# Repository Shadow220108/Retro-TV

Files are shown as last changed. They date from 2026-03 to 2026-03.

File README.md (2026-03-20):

<<<<<<< HEAD
| Retro-TV |
| --- |
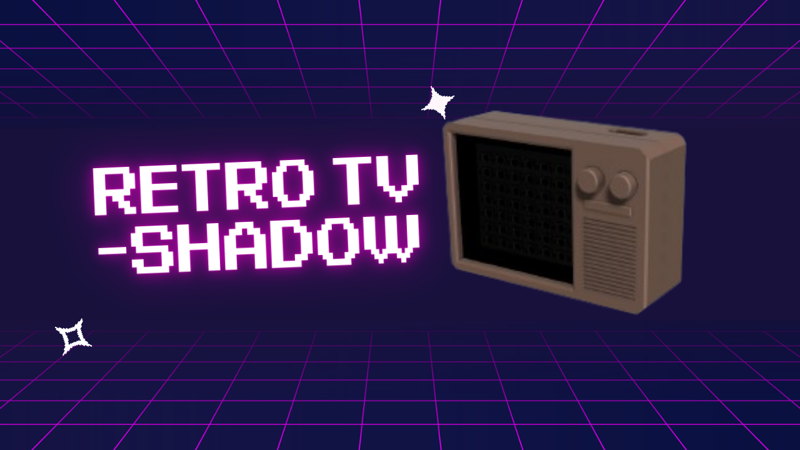
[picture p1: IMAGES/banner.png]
Banner
|  | 

Its a LED Matrix display of 7x7 LEDs, in a vintage television style case!  

### PCB
The PCB is designed to be compact with about 50 LEDs in just about 60mm of space
| LED Matrix |
| --- |
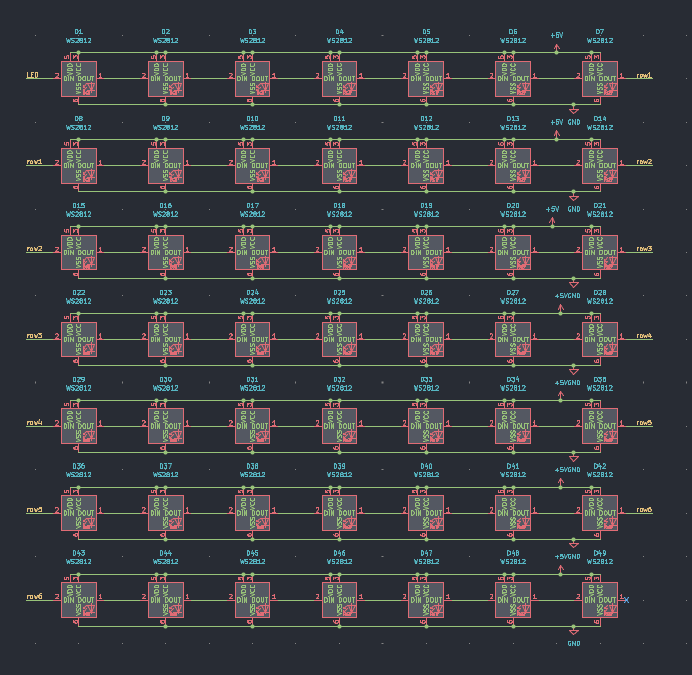
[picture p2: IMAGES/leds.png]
Schematics
|  | 

| MCU |
| --- |
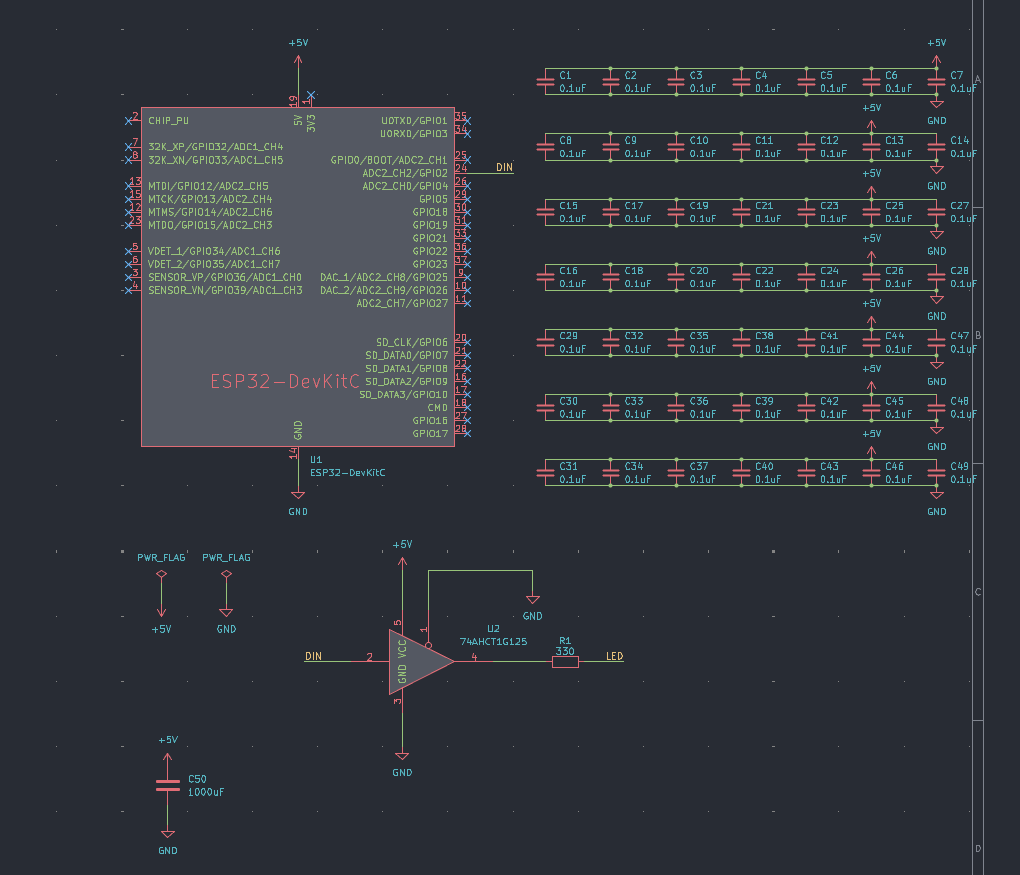
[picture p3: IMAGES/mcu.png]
PCB All Layers
|  |

| PCB (All Layers)|
| --- |
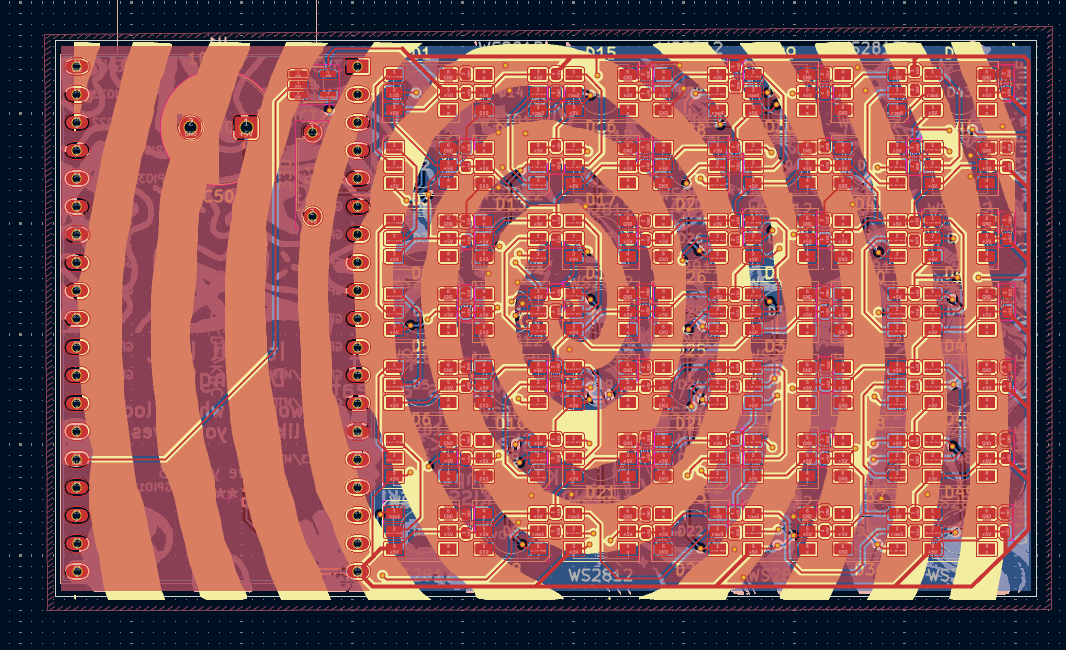
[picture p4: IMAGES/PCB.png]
|  |
| --- |
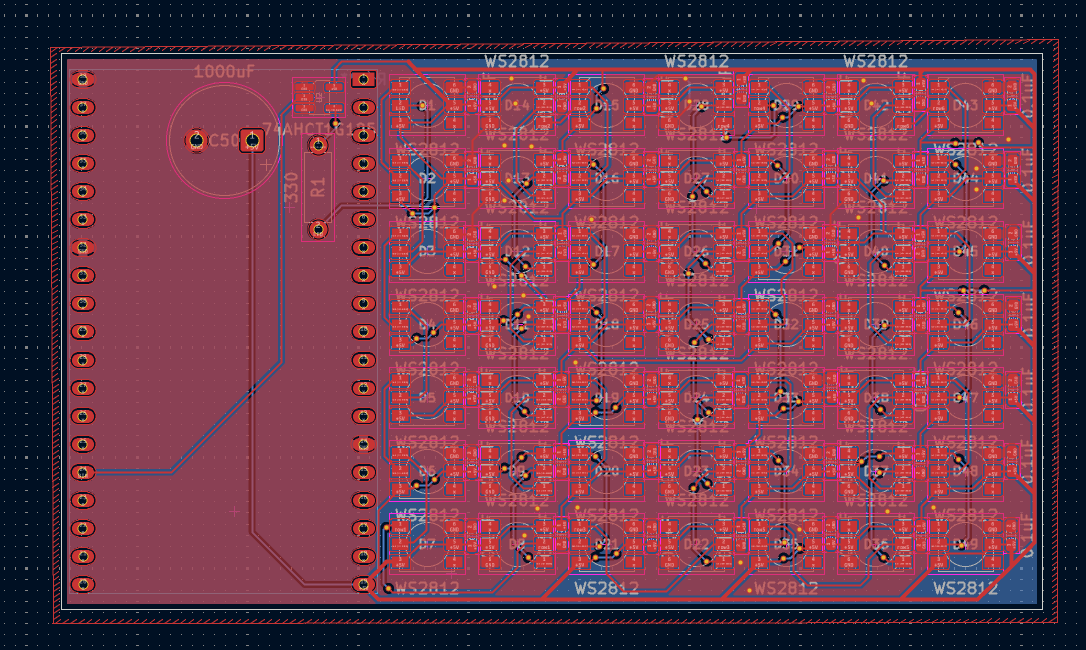
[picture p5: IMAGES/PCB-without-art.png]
|  |

| PS : Some PCB art|
| --- |
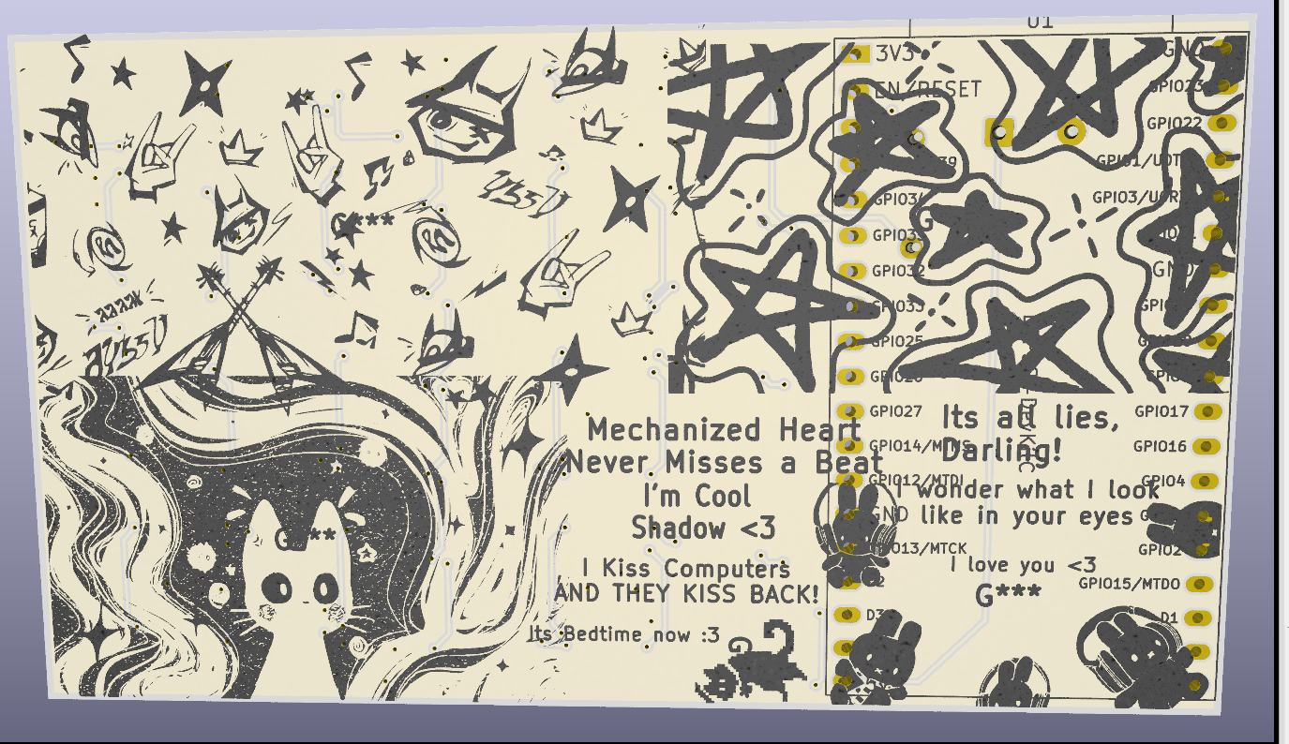
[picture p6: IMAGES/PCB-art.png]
|  |
| --- |
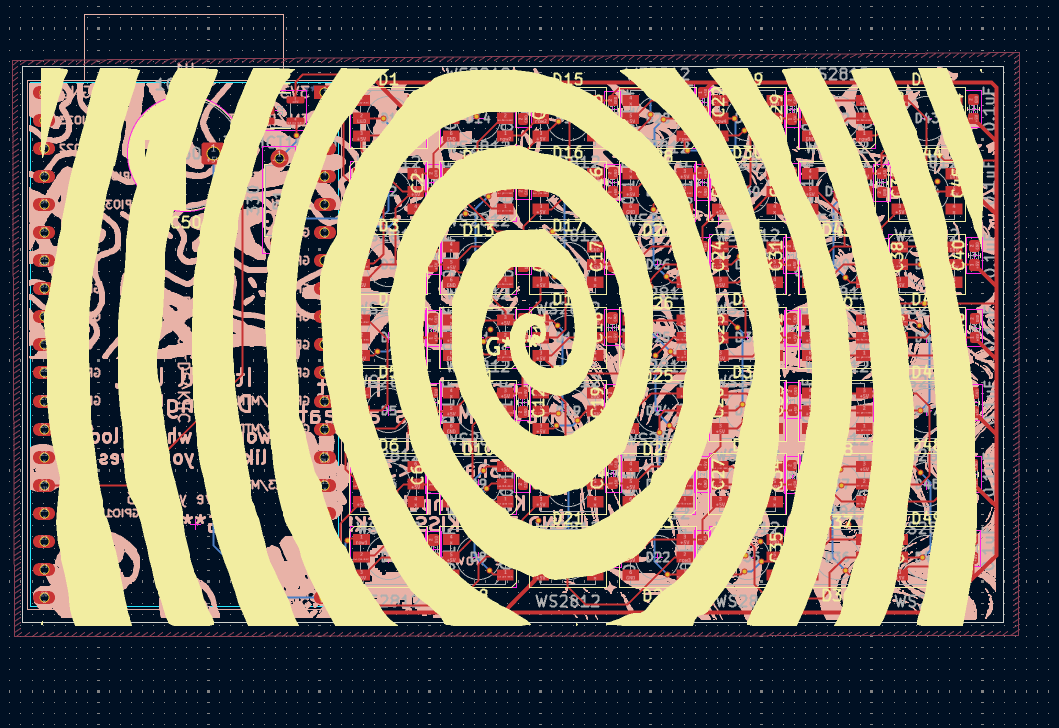
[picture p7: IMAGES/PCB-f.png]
|  |
| --- |
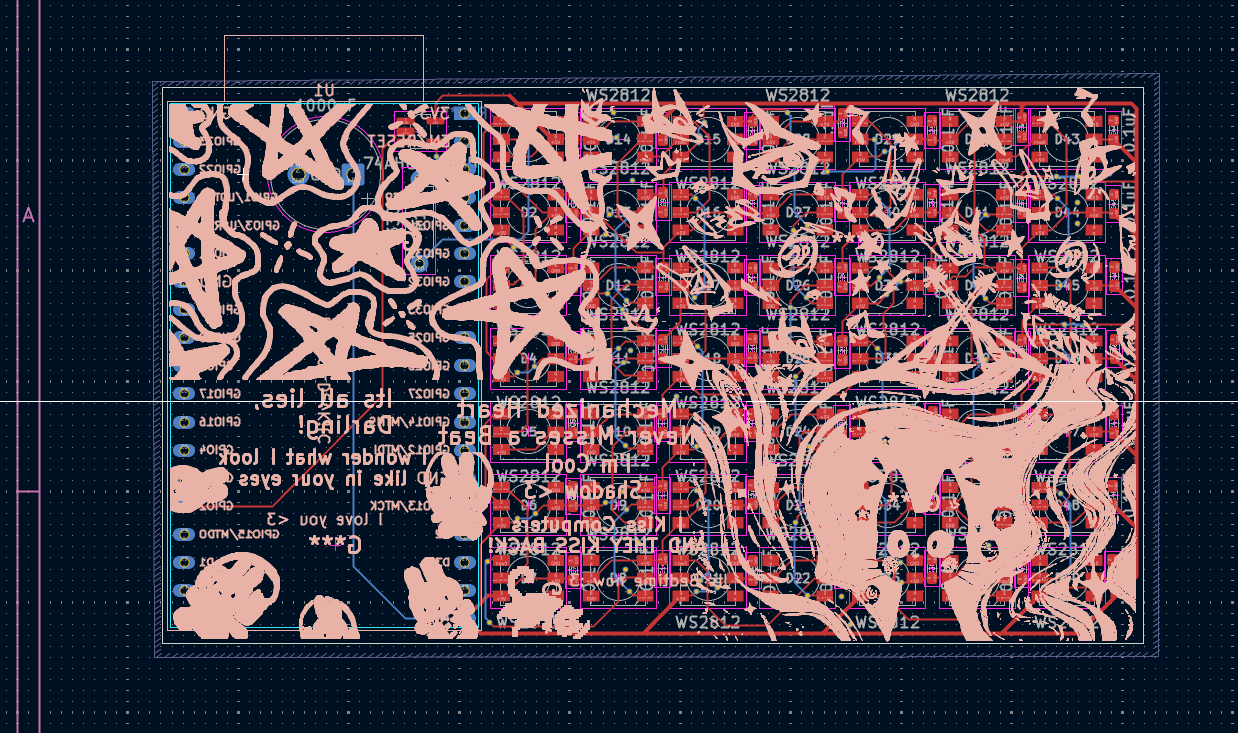
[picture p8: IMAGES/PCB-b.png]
|  |

## Case

The case is designed to be 3D printed and attached with magnets. The bottom case, top case, plate, and knob are all designed to be printed.

| CAD|
| --- |
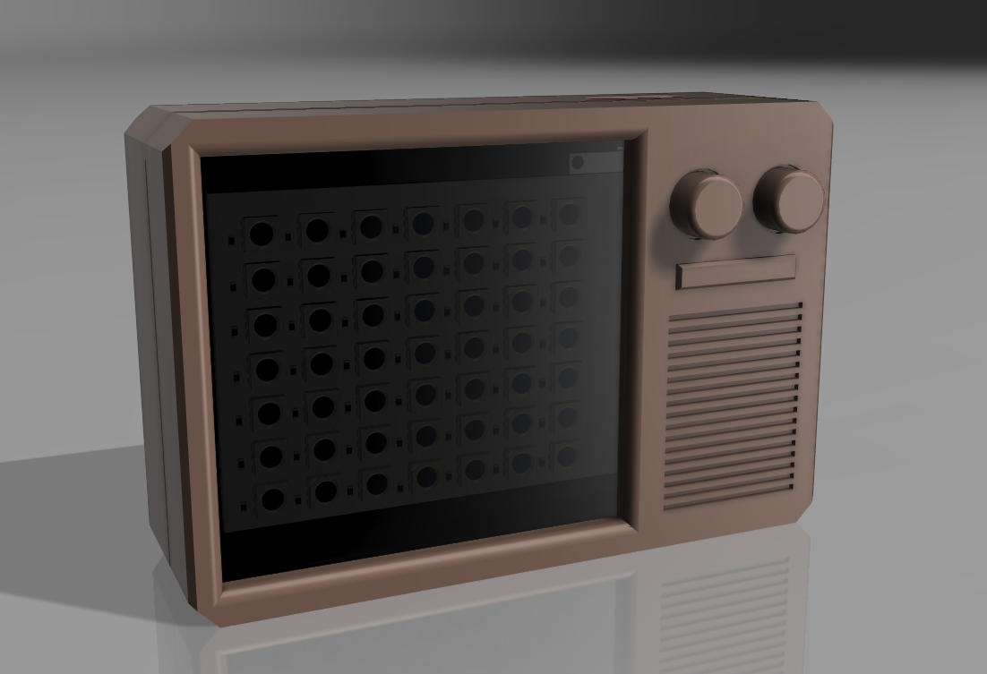
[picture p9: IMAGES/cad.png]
|  |
| --- |
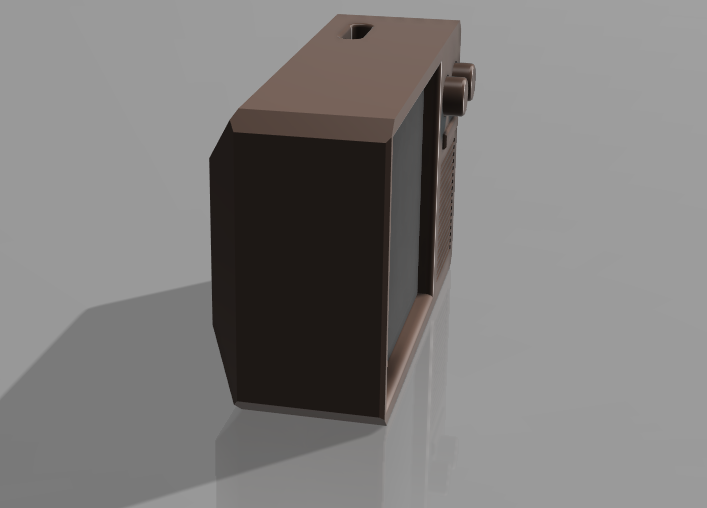
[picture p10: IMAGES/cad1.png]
|  |

## BOM 
|Name |Purpose |Cost Per Item (USD)|Quantity|Total (USD)|Link |Distributor |
|---|---|---|---|---|---|---|
|3D Prints |to get prints from #printing-legion |5.00 |1 |5.00 | |#printing-legion|
|Soldering Hotplate |To solder the mini leds |0.00 |1 |0.00 | |Self sourced |
|Soldering paste |to solder the smd components |4.50 |1 |4.50 |https://www.amazon.in/gp/product/B0F9VTZJ5R?smid=A32I52VHFPY5IG&psc=1 |Amazon |
|Alkin 65W adapter |To use the soldering hotplate to solder|8.54 |1 |8.54 |https://www.amazon.in/AILKIN-Charging-Adapter-Multi-Port-Compatible/dp/B0GH81K2LK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|Amazon |
|Neodimium magnets |to attach the top and bottom case |3.00 |1 |3.00 |https://www.amazon.in/gp/product/B0G2SW9GZL?smid=AP7MBNLZTN3FQ&psc=1 |amazon |
|330 ohm resistor ( 10 moq ) |to not burst the leds |0.11 |1 |0.11 |https://robu.in/product/330-ohm-1w-metal-film-resistor-pack-of-40/ |robu.in |
|1000uF capacitor |Bulk capacitor |0.11 |1 |0.11 |https://robu.in/product/1000uf-25v-electrolytic-capacitor-dip-pack-of-5/ |robu.in |
|0.1uF capacitors |to reduce electrical noise |0.07 |50 |3.75 |https://probots.co.in/0-1-uf-50v-smd-ceramic-capacitor-0603-package.html |probots.co |
|74AHCT1G125GV |Level shifter for LEDs |0.16 |1 |0.16 |https://robu.in/product/74ahct1g125gv125-nexperia-1-8ma-4-5v5-5v-8ma-1-sot-753-buffers-drivers-receivers-transceivers-rohs/ |robu,in |
|SMD 5050 LEDs |For the display |0.04 |50 |2.00 |https://www.flyrobo.in/5050-red-green-blue-rgb-smd-led |flyrobo.in |
|ESP32 Devboard |MCU to control the LEDs |4.62 |1 |4.62 |https://www.flyrobo.in/esp-wroom-32-nodemcu-module?search=esp32&description=true |flyrobo.in |
|PCB ( 5 MOQ ) |to solder all the components |13.02 |1 |13.02 | |JLCPCB |
=======
| Retro-TV |
| --- |
| Banner | 

Its a LED Matrix display of 7x7 LEDs, in a vintage television style case!  

### PCB
The PCB is designed to be compact with about 50 LEDs in just about 60mm of space
| LED Matrix |
| --- |
| Schematics | 

| MCU |
| --- |
| PCB All Layers |

| PCB (All Layers)|
| --- |
| PCB1 |
| --- |
| PCB1 |

| PS : Some PCB art|
| --- |
| Quotes |
| --- |
| Quotes |
| --- |
| Quotes |

## Case

The case is designed to be 3D printed and attached with magnets. The bottom case, top case, plate, and knob are all designed to be printed.

| CAD|
| --- |
| Case Full |
| --- |
| Case Full |

## BOM 
|Name |Purpose |Cost Per Item (USD)|Quantity|Total (USD)|Link |Distributor |
|---|---|---|---|---|---|---|
|3D Prints |to get prints from #printing-legion |5.00 |1 |5.00 | |#printing-legion|
|Soldering Hotplate |To solder the mini leds |0.00 |1 |0.00 | |Self sourced |
|Soldering paste |to solder the smd components |4.50 |1 |4.50 |https://www.amazon.in/gp/product/B0F9VTZJ5R?smid=A32I52VHFPY5IG&psc=1 |Amazon |
|Alkin 65W adapter |To use the soldering hotplate to solder|8.54 |1 |8.54 |https://www.amazon.in/AILKIN-Charging-Adapter-Multi-Port-Compatible/dp/B0GH81K2LK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|Amazon |
|Neodimium magnets |to attach the top and bottom case |3.00 |1 |3.00 |https://www.amazon.in/gp/product/B0G2SW9GZL?smid=AP7MBNLZTN3FQ&psc=1 |amazon |
|330 ohm resistor ( 10 moq ) |to not burst the leds |0.11 |1 |0.11 |https://robu.in/product/330-ohm-1w-metal-film-resistor-pack-of-40/ |robu.in |
|1000uF capacitor |Bulk capacitor |0.11 |1 |0.11 |https://robu.in/product/1000uf-25v-electrolytic-capacitor-dip-pack-of-5/ |robu.in |
|0.1uF capacitors |to reduce electrical noise |0.07 |50 |3.75 |https://probots.co.in/0-1-uf-50v-smd-ceramic-capacitor-0603-package.html |probots.co |
|74AHCT1G125GV |Level shifter for LEDs |0.16 |1 |0.16 |https://robu.in/product/74ahct1g125gv125-nexperia-1-8ma-4-5v5-5v-8ma-1-sot-753-buffers-drivers-receivers-transceivers-rohs/ |robu,in |
|SMD 5050 LEDs |For the display |0.04 |50 |2.00 |https://www.flyrobo.in/5050-red-green-blue-rgb-smd-led |flyrobo.in |
|ESP32 Devboard |MCU to control the LEDs |4.62 |1 |4.62 |https://www.flyrobo.in/esp-wroom-32-nodemcu-module?search=esp32&description=true |flyrobo.in |
|PCB ( 5 MOQ ) |to solder all the components |13.02 |1 |13.02 | |JLCPCB |
>>>>>>> c8a452447a518745ea2085dd8981138584917547

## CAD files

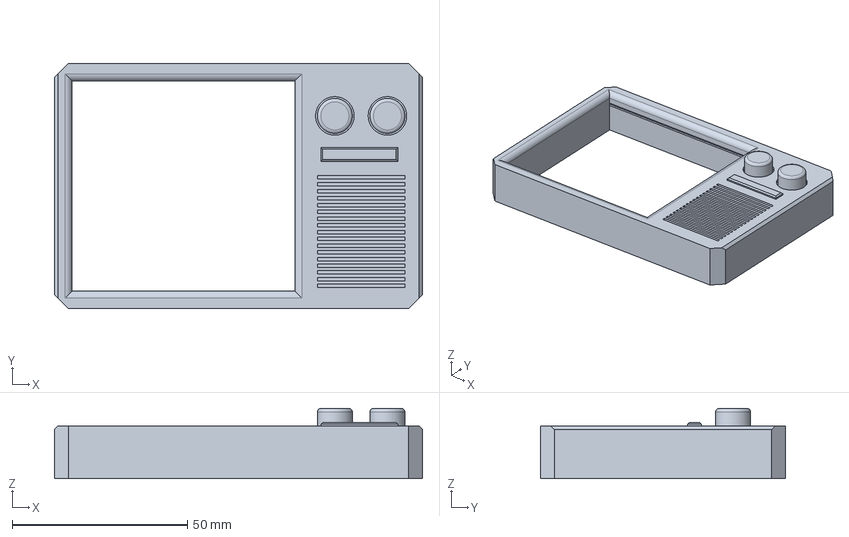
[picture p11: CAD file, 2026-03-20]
CAD/top.step
105.0 x 70.0 x 20.0 mm

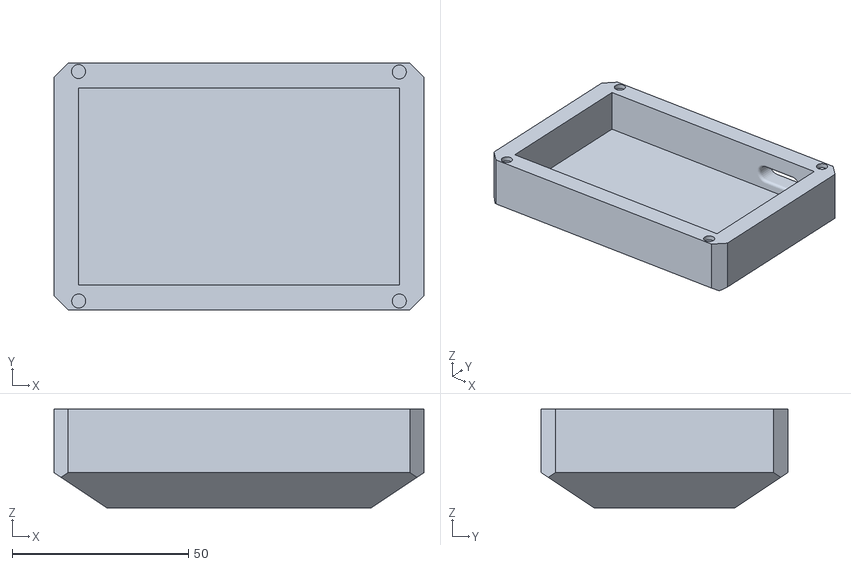
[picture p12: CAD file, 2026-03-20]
PRODUCTION/bottom.stl
105.0 x 70.0 x 28.0

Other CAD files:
CAD/bottom.step
PRODUCTION/top.stl

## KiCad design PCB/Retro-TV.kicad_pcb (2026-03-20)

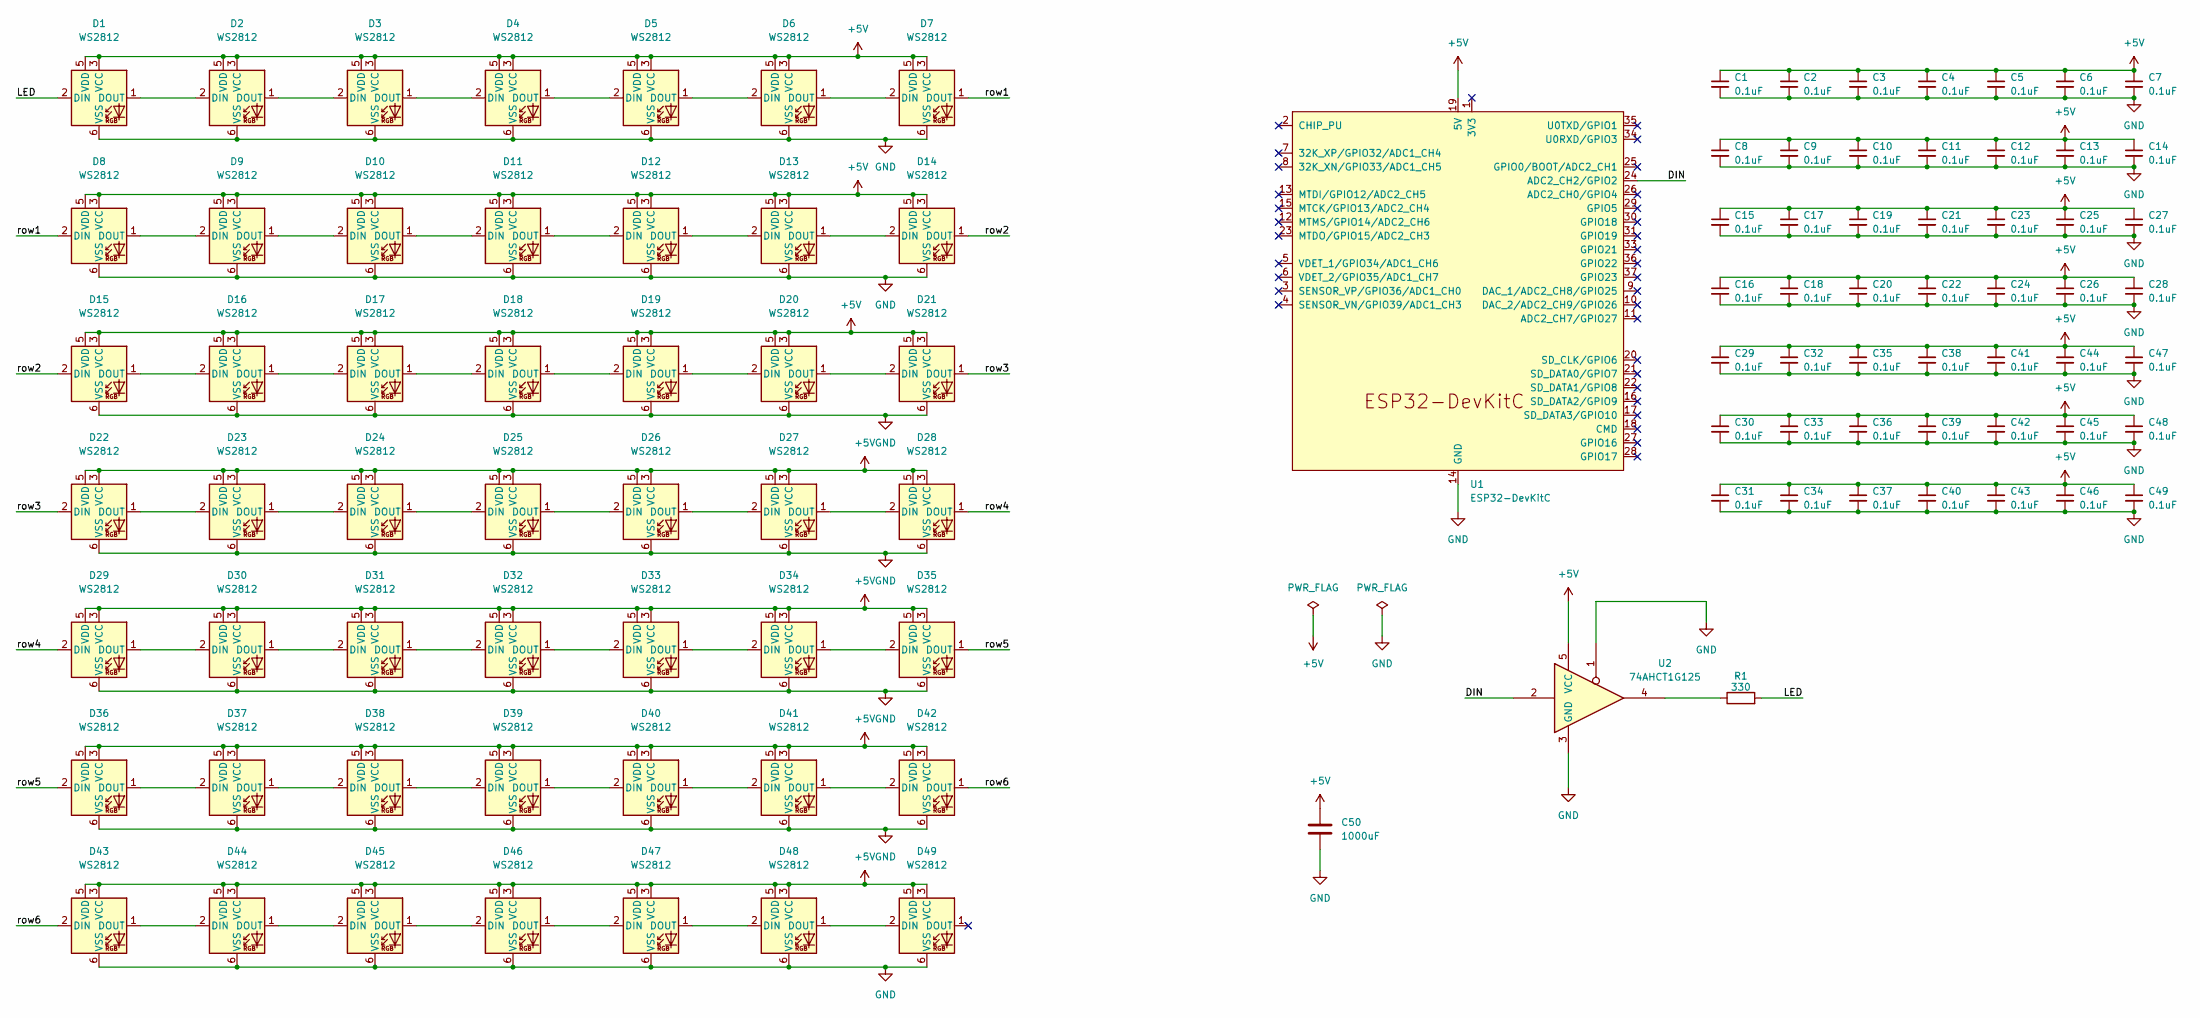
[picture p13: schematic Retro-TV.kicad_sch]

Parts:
C1, C2, C3, C4, C5, C6, C7, C8, C9, C10, C11, C12, C13, C14, C15, C16, C17, C18, C19, C20, C21, C22, C23, C24, C25, C26, C27, C28, C29, C30, C31, C32, C33, C34, C35, C36, C37, C38, C39, C40, C41, C42, C43, C44, C45, C46, C47, C48, C49: 0.1uF; C_0603_1608Metric_Pad1.08x0.95mm_HandSolder
C50: 1000uF; CP_Radial_D10.0mm_P5.00mm
D1, D2, D3, D4, D5, D6, D7, D8, D9, D10, D11, D12, D13, D14, D15, D16, D17, D18, D19, D20, D21, D22, D23, D24, D25, D26, D27, D28, D29, D30, D31, D32, D33, D34, D35, D36, D37, D38, D39, D40, D41, D42, D43, D44, D45, D46, D47, D48, D49: WS2812; LED_WS2812_PLCC6_5.0x5.0mm_P1.6mm
R1: 330; R_Axial_DIN0207_L6.3mm_D2.5mm_P7.62mm_Horizontal
U1: ESP32-DevKitC
U2: 74AHCT1G125; SOT-23-5_HandSoldering

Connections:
+5V: C1.1, C2.1, C3.1, C4.1, C5.1, C6.1, C7.1, C8.1, C9.1, C10.1, C11.1, C12.1, C13.1, C14.1, C15.1, C16.1, C17.1, C18.1, C19.1, C20.1, C21.1, C22.1, C23.1, C24.1, C25.1, C26.1, C27.1, C28.1, C29.1, C30.1, C31.1, C32.1, C33.1, C34.1, C35.1, C36.1, C37.1, C38.1, C39.1, C40.1, C41.1, C42.1, C43.1, C44.1, C45.1, C46.1, C47.1, C48.1, C49.1, C50.1, D1.3 (VCC), D1.5 (VDD), D2.3 (VCC), D2.5 (VDD), D3.3 (VCC), D3.5 (VDD), D4.3 (VCC), D4.5 (VDD), D5.3 (VCC), D5.5 (VDD), D6.3 (VCC), D6.5 (VDD), D7.3 (VCC), D7.5 (VDD), D8.3 (VCC), D8.5 (VDD), D9.3 (VCC), D9.5 (VDD), D10.3 (VCC), D10.5 (VDD), D11.3 (VCC), D11.5 (VDD), D12.3 (VCC), D12.5 (VDD), D13.3 (VCC), D13.5 (VDD), D14.3 (VCC), D14.5 (VDD), D15.3 (VCC), D15.5 (VDD), D16.3 (VCC), D16.5 (VDD), D17.3 (VCC), D17.5 (VDD), D18.3 (VCC), D18.5 (VDD), D19.3 (VCC), D19.5 (VDD), D20.3 (VCC), D20.5 (VDD), D21.3 (VCC), D21.5 (VDD), D22.3 (VCC), D22.5 (VDD), D23.3 (VCC), D23.5 (VDD), D24.3 (VCC), D24.5 (VDD), D25.3 (VCC), D25.5 (VDD), D26.3 (VCC), D26.5 (VDD), D27.3 (VCC), D27.5 (VDD), D28.3 (VCC), D28.5 (VDD), D29.3 (VCC), D29.5 (VDD), D30.3 (VCC), D30.5 (VDD), D31.3 (VCC), D31.5 (VDD), D32.3 (VCC), D32.5 (VDD), D33.3 (VCC), D33.5 (VDD), D34.3 (VCC), D34.5 (VDD), D35.3 (VCC), D35.5 (VDD), D36.3 (VCC), D36.5 (VDD), D37.3 (VCC), D37.5 (VDD), D38.3 (VCC), D38.5 (VDD), D39.3 (VCC), D39.5 (VDD), D40.3 (VCC), D40.5 (VDD), D41.3 (VCC), D41.5 (VDD), D42.3 (VCC), D42.5 (VDD), D43.3 (VCC), D43.5 (VDD), D44.3 (VCC), D44.5 (VDD), D45.3 (VCC), D45.5 (VDD), D46.3 (VCC), D46.5 (VDD), D47.3 (VCC), D47.5 (VDD), D48.3 (VCC), D48.5 (VDD), D49.3 (VCC), D49.5 (VDD), U1.19 (5V), U2.5 (VCC)
/DIN: U1.24 (ADC2_CH2/GPIO2), U2.2
/LED: D1.2 (DIN), R1.2
/row1: D7.1 (DOUT), D8.2 (DIN)
/row2: D14.1 (DOUT), D15.2 (DIN)
/row3: D21.1 (DOUT), D22.2 (DIN)
/row4: D28.1 (DOUT), D29.2 (DIN)
/row5: D35.1 (DOUT), D36.2 (DIN)
/row6: D42.1 (DOUT), D43.2 (DIN)
GND: C1.2, C2.2, C3.2, C4.2, C5.2, C6.2, C7.2, C8.2, C9.2, C10.2, C11.2, C12.2, C13.2, C14.2, C15.2, C16.2, C17.2, C18.2, C19.2, C20.2, C21.2, C22.2, C23.2, C24.2, C25.2, C26.2, C27.2, C28.2, C29.2, C30.2, C31.2, C32.2, C33.2, C34.2, C35.2, C36.2, C37.2, C38.2, C39.2, C40.2, C41.2, C42.2, C43.2, C44.2, C45.2, C46.2, C47.2, C48.2, C49.2, C50.2, D1.6 (VSS), D2.6 (VSS), D3.6 (VSS), D4.6 (VSS), D5.6 (VSS), D6.6 (VSS), D7.6 (VSS), D8.6 (VSS), D9.6 (VSS), D10.6 (VSS), D11.6 (VSS), D12.6 (VSS), D13.6 (VSS), D14.6 (VSS), D15.6 (VSS), D16.6 (VSS), D17.6 (VSS), D18.6 (VSS), D19.6 (VSS), D20.6 (VSS), D21.6 (VSS), D22.6 (VSS), D23.6 (VSS), D24.6 (VSS), D25.6 (VSS), D26.6 (VSS), D27.6 (VSS), D28.6 (VSS), D29.6 (VSS), D30.6 (VSS), D31.6 (VSS), D32.6 (VSS), D33.6 (VSS), D34.6 (VSS), D35.6 (VSS), D36.6 (VSS), D37.6 (VSS), D38.6 (VSS), D39.6 (VSS), D40.6 (VSS), D41.6 (VSS), D42.6 (VSS), D43.6 (VSS), D44.6 (VSS), D45.6 (VSS), D46.6 (VSS), D47.6 (VSS), D48.6 (VSS), D49.6 (VSS), U1.14 (GND), U1.32 (GND), U1.38 (GND), U2.1, U2.3 (GND)
unnamed: D1.1 (DOUT), D2.2 (DIN)
unnamed: D2.1 (DOUT), D3.2 (DIN)
unnamed: D3.1 (DOUT), D4.2 (DIN)
unnamed: D4.1 (DOUT), D5.2 (DIN)
unnamed: D5.1 (DOUT), D6.2 (DIN)
unnamed: D6.1 (DOUT), D7.2 (DIN)
unnamed: D8.1 (DOUT), D9.2 (DIN)
unnamed: D9.1 (DOUT), D10.2 (DIN)
unnamed: D10.1 (DOUT), D11.2 (DIN)
unnamed: D11.1 (DOUT), D12.2 (DIN)
unnamed: D12.1 (DOUT), D13.2 (DIN)
unnamed: D13.1 (DOUT), D14.2 (DIN)
unnamed: D15.1 (DOUT), D16.2 (DIN)
unnamed: D16.1 (DOUT), D17.2 (DIN)
unnamed: D17.1 (DOUT), D18.2 (DIN)
unnamed: D18.1 (DOUT), D19.2 (DIN)
unnamed: D19.1 (DOUT), D20.2 (DIN)
unnamed: D20.1 (DOUT), D21.2 (DIN)
unnamed: D22.1 (DOUT), D23.2 (DIN)
unnamed: D23.1 (DOUT), D24.2 (DIN)
unnamed: D24.1 (DOUT), D25.2 (DIN)
unnamed: D25.1 (DOUT), D26.2 (DIN)
unnamed: D26.1 (DOUT), D27.2 (DIN)
unnamed: D27.1 (DOUT), D28.2 (DIN)
unnamed: D29.1 (DOUT), D30.2 (DIN)
unnamed: D30.1 (DOUT), D31.2 (DIN)
unnamed: D31.1 (DOUT), D32.2 (DIN)
unnamed: D32.1 (DOUT), D33.2 (DIN)
unnamed: D33.1 (DOUT), D34.2 (DIN)
unnamed: D34.1 (DOUT), D35.2 (DIN)
unnamed: D36.1 (DOUT), D37.2 (DIN)
unnamed: D37.1 (DOUT), D38.2 (DIN)
unnamed: D38.1 (DOUT), D39.2 (DIN)
unnamed: D39.1 (DOUT), D40.2 (DIN)
unnamed: D40.1 (DOUT), D41.2 (DIN)
unnamed: D41.1 (DOUT), D42.2 (DIN)
unnamed: D43.1 (DOUT), D44.2 (DIN)
unnamed: D44.1 (DOUT), D45.2 (DIN)
unnamed: D45.1 (DOUT), D46.2 (DIN)
unnamed: D46.1 (DOUT), D47.2 (DIN)
unnamed: D47.1 (DOUT), D48.2 (DIN)
unnamed: D48.1 (DOUT), D49.2 (DIN)
unnamed: R1.1, U2.4

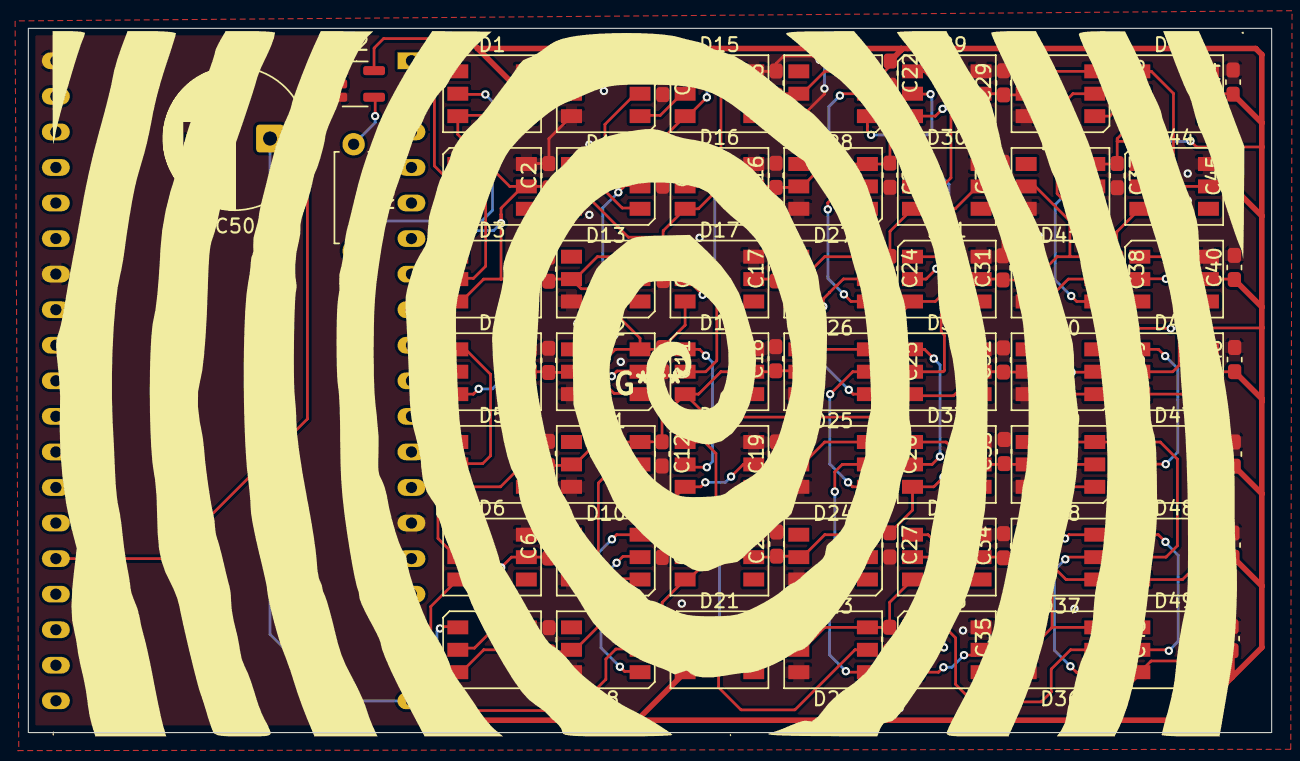
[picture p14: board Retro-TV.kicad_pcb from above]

Board: 2 copper layers, 88.8 x 50.3 mm, 102 parts (1 on the bottom side), 53 nets.

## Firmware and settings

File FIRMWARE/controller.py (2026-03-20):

#!/usr/bin/env python3
"""ESP32 Matrix LED Controller — local web UI over USB serial."""

import serial
import time
import threading
from flask import Flask, request, jsonify

SERIAL_PORT = "/dev/cu.usbmodem101"
BAUD_RATE = 115200

app = Flask(__name__)
ser = None
lock = threading.Lock()

def get_serial():
    global ser
    if ser is None or not ser.is_open:
        ser = serial.Serial(SERIAL_PORT, BAUD_RATE, timeout=1,
                           write_timeout=1, dsrdtr=False, rtscts=False)
        ser.dtr = False
        ser.rts = False
        time.sleep(0.5)
        ser.reset_input_buffer()
    return ser

def send_cmd(cmd):
    with lock:
        try:
            s = get_serial()
            data = f"{cmd}\n".encode("ascii")
            s.write(data)
            s.flush()
            time.sleep(0.1)
            # Read response
            resp = ""
            while s.in_waiting:
                resp += s.read(s.in_waiting).decode("ascii", errors="ignore")
            print(f"  -> {cmd}  |  <- {resp.strip()}")
            return True
        except Exception as e:
            print(f"Serial error: {e}")
            global ser
            ser = None
            return False

HTML = """<!DOCTYPE html>
<html>
<head>
<meta name="viewport" content="width=device-width,initial-scale=1">
<title>ESP32 Matrix</title>
<style>
*{box-sizing:border-box;margin:0;padding:0}
body{font-family:-apple-system,sans-serif;background:#111;color:#fff;
  display:flex;justify-content:center;padding:20px}
.c{max-width:420px;width:100%}
h1{text-align:center;margin-bottom:24px;font-size:1.5em}
.color-pick{width:100%;height:90px;border:none;border-radius:14px;
  cursor:pointer;margin-bottom:18px}
.presets{display:grid;grid-template-columns:repeat(4,1fr);gap:10px;margin-bottom:18px}
.preset{width:100%;aspect-ratio:1;border-radius:50%;border:3px solid #333;
  cursor:pointer;transition:.2s}
.preset:hover{transform:scale(1.15);border-color:#fff}
.modes{display:grid;grid-template-columns:1fr 1fr;gap:10px;margin-bottom:18px}
.btn{padding:14px;border:2px solid #333;border-radius:12px;background:#222;
  color:#fff;font-size:1em;cursor:pointer;text-align:center;transition:.2s}
.btn.active{border-color:#0af;color:#0af}
.btn:active{transform:scale(.95)}
.slider-group{margin-bottom:18px}
.slider-group label{display:block;margin-bottom:8px;color:#888;font-size:.85em}
input[type=range]{width:100%;accent-color:#0af;height:32px}
.off-btn{width:100%;padding:16px;border-radius:12px;border:2px solid #c00;
  background:#200;color:#f66;font-size:1.1em;cursor:pointer;font-weight:600}
.off-btn.is-off{border-color:#0a0;background:#020;color:#0f0}
.status{text-align:center;margin-top:12px;color:#555;font-size:.8em}
</style>
</head>
<body>
<div class="c">
<h1>LED Matrix</h1>

<input type="color" id="cp" class="color-pick" value="#ff0064">

<div class="presets">
  <div class="preset" style="background:#ff0000" onclick="c('red')"></div>
  <div class="preset" style="background:#00ff00" onclick="c('green')"></div>
  <div class="preset" style="background:#0000ff" onclick="c('blue')"></div>
  <div class="preset" style="background:#ffffff" onclick="c('white')"></div>
  <div class="preset" style="background:#8000ff" onclick="c('purple')"></div>
  <div class="preset" style="background:#ff5000" onclick="c('orange')"></div>
  <div class="preset" style="background:#00ffff" onclick="c('cyan')"></div>
  <div class="preset" style="background:#ff0064" onclick="c('pink')"></div>
</div>

<div class="modes">
  <div class="btn active" id="m0" onclick="setMode(0)">Solid</div>
  <div class="btn" id="m1" onclick="setMode(1)">Rainbow</div>
  <div class="btn" id="m2" onclick="setMode(2)">Breathe</div>
  <div class="btn" id="m3" onclick="setMode(3)">Wave</div>
</div>

<div class="slider-group">
  <label>Brightness: <span id="bv">5</span></label>
  <input type="range" id="br" min="1" max="30" value="5"
    oninput="document.getElementById('bv').textContent=this.value"
    onchange="c('bright '+this.value)">
</div>

<button class="off-btn" id="toggle" onclick="toggleLeds()">Turn Off</button>
<div class="status" id="st">Connected via USB</div>
</div>
<script>
let isOn=true, curMode=0;
const cp=document.getElementById('cp');
const modes=['color #ff0064','rainbow','breathe','wave'];

cp.addEventListener('input',function(){
  c('color #'+this.value.substring(1));
  setActive(0);
});

function c(cmd){
  document.getElementById('st').textContent='Sending...';
  fetch('/cmd',{method:'POST',headers:{'Content-Type':'application/json'},
    body:JSON.stringify({cmd:cmd})})
  .then(r=>r.json())
  .then(d=>{document.getElementById('st').textContent=d.ok?'OK: '+cmd:'Error!'})
  .catch(()=>{document.getElementById('st').textContent='Connection error'});
}

function setMode(m){
  curMode=m;
  setActive(m);
  if(m==0) c('color #'+cp.value.substring(1));
  else if(m==1) c('rainbow');
  else if(m==2) c('breathe');
  else if(m==3) c('wave');
}

function setActive(m){
  for(let i=0;i<4;i++) document.getElementById('m'+i).classList.toggle('active',i==m);
}

function toggleLeds(){
  isOn=!isOn;
  const b=document.getElementById('toggle');
  b.textContent=isOn?'Turn Off':'Turn On';
  b.classList.toggle('is-off',!isOn);
  c(isOn?'on':'off');
}
</script>
</body>
</html>"""

@app.route("/")
def index():
    return HTML

@app.route("/cmd", methods=["POST"])
def cmd():
    data = request.get_json()
    command = data.get("cmd", "")
    ok = send_cmd(command)
    return jsonify({"ok": ok, "cmd": command})

if __name__ == "__main__":
    print(f"Connecting to {SERIAL_PORT}...")
    get_serial()
    print("Serial connected!")
    print()
    print(">>> Open http://localhost:5555")
    print()
    app.run(host="0.0.0.0", port=5555, debug=False)

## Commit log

2026-03-20 Upload files from local repo
    [Retro-TV-bom.csv, Retro-TV.kicad_pcb, Retro-TV.kicad_sch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]
2026-03-20 Added production
    [bottom.stl, top.stl]
